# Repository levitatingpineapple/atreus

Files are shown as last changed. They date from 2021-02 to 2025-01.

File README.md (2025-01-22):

# Atreus

A keyboard with 42 key [Atreus](https://atreus.technomancy.us) layout. Uses [Kailh Choc](http://www.kailh.com/en/Products/Ks/CS/) low profile switches with hot-swap sockets. Compatible with ProMicro type controllers, but designed to be used with [Nice!Nano](https://nicekeyboards.com/nice-nano). Capable of n-key rollover. There is enough spacing between keys to fit all of the commonly available keycaps - transparent, flat and concave.

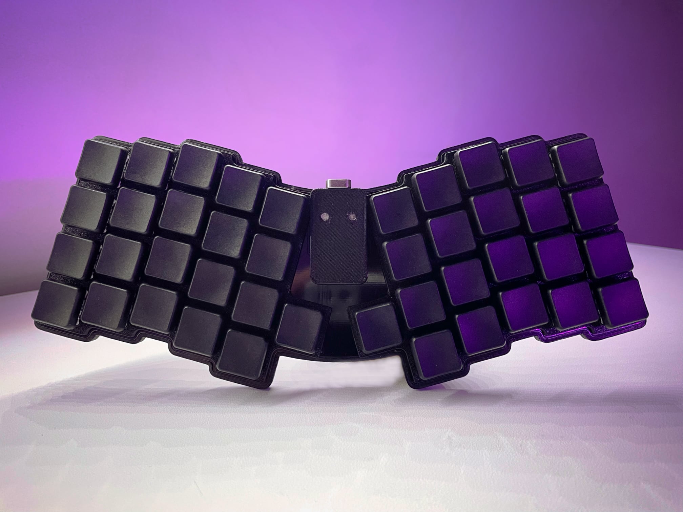
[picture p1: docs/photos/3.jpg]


## Firmware

[Nice!Nano](https://nicekeyboards.com/nice-nano) is best supported by [ZMK](https://zmk.dev) Configuration for this board is hosted in the [levitatingpineapple/atreus-zmk](https://github.com/levitatingpineapple/atreus-zmk) repo.
To build a different keymap - clone the repo and update `.keymap` file as needed.
The firmware will be build using [Build ZMK firmware](https://github.com/levitatingpineapple/atreus-zmk/actions/workflows/build.yml) action.

## Materials

| Name | Part | Size | Amount |
| --- | --- | --- | --- |
| Switch | [CPG135001D0X](docs/switch.pdf)  | - | 42 |
| Socket | [CPG135001S30](docs/socket.pdf)  | - | 42 |
| Diode | [1N4148](docs/diode.pdf) | SOD123 | 42 |
| Controller | [nice!nano](docs/controller.png) | - | 1 |
| Battery | XZK 301230 | 30x12x3.0mm | 1 |
| Bolt | M2 Hex | 4mm | 8 |
| Machine Headers | Mill-Max | 13p 3mm | 2 |

### PCB

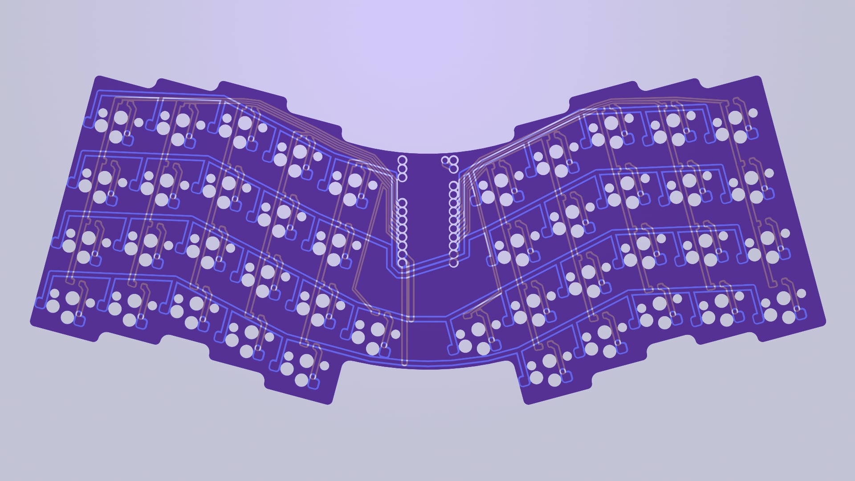
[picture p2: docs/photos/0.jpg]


- ⚠️ No power switch for the battery
- For every switch has a diode, soldered where an backlight LED would normally be located, providing n-key rollover.

### Sockets

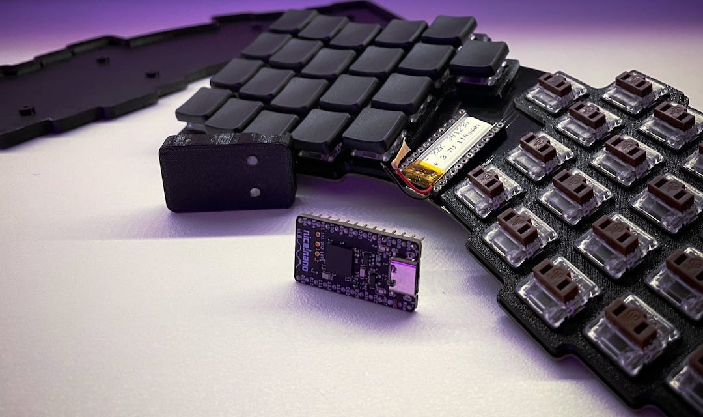
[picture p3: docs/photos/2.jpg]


- The PCB has 1.5mm wide holes for mounting the controller socket. This allows soldering machine headers flush with the board. The nice!nano controller originally ships with low profile headers, which won't fit the battery underneath the controller, if soldered in this manner. Therefore a pair of 3mm tall headers had to be separately ordered.

### Case

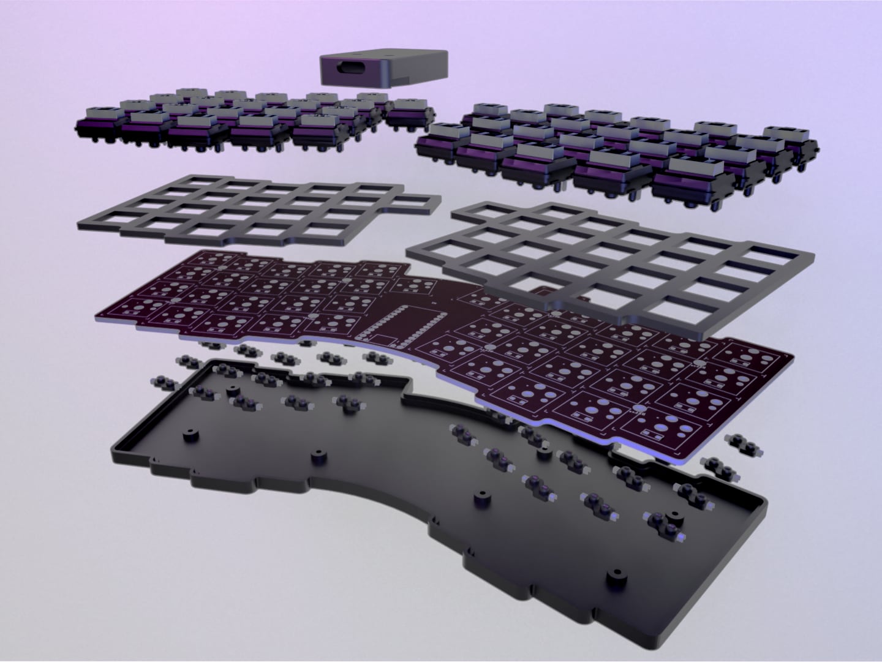
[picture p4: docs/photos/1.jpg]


- All 3d printing was done with 0.4mm nozzle at 0.2mm layer height from PETG.
- The bottom case is attached using eight 4mm long M2 bolts.
- Added feet using 1mm thick rubber tape

### Led

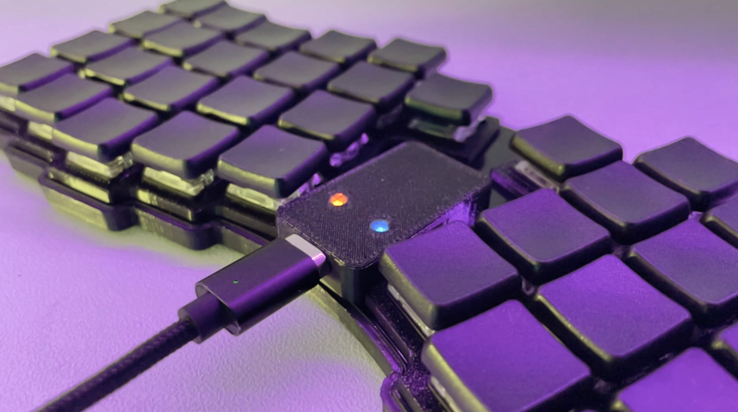
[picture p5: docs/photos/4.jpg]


- In the nice!nano's cover there are two openings for the LEDs. They can be filled with a dab of hot-glue before the print is removed form the bed to get a more diffused look _...for science, you monster._

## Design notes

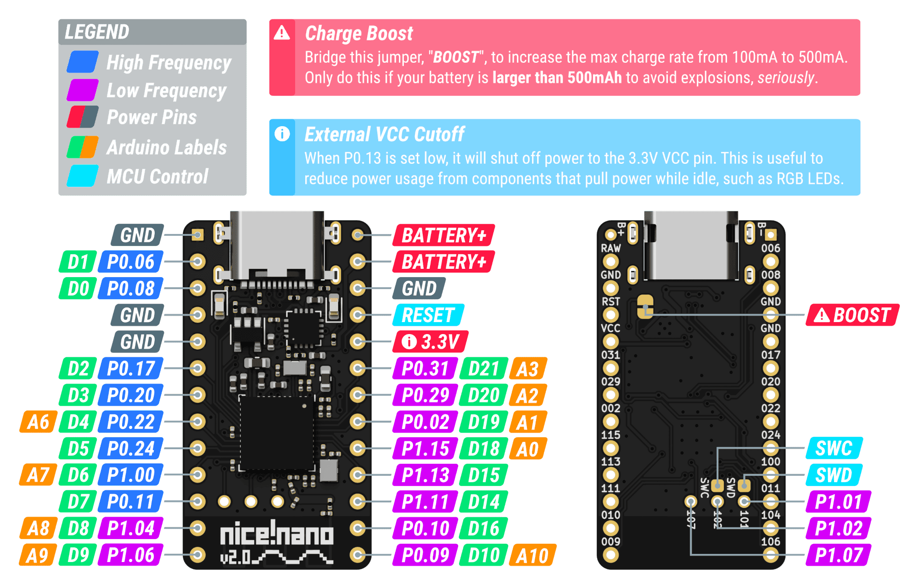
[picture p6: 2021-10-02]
docs/controller.png

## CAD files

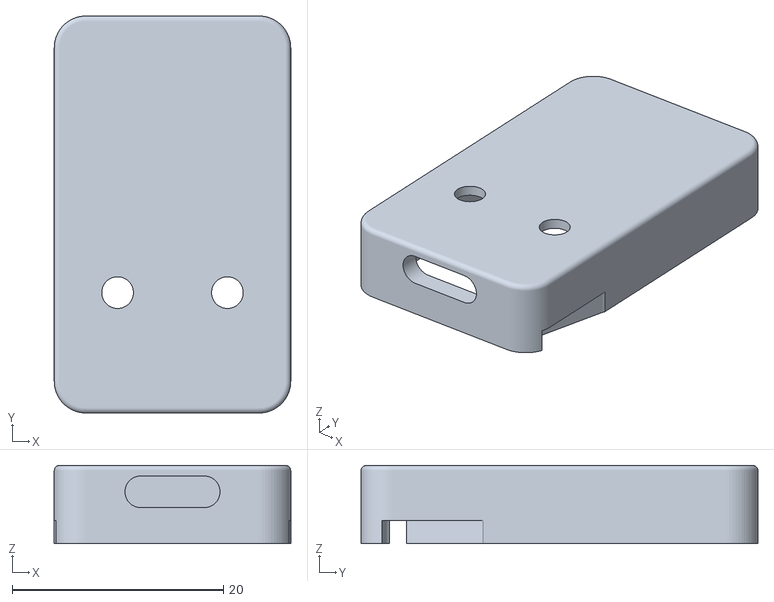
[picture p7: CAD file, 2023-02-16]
export/case/controller.stl
22.4 x 37.6 x 7.40

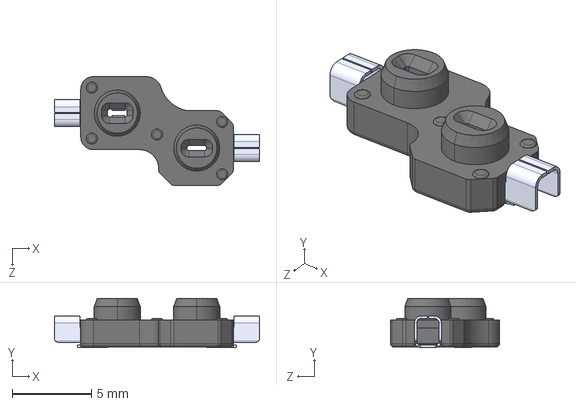
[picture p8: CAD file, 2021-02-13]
project/3DModels/choc_socket.step
12.9 x 3.09 x 6.85 mm
pin x 2
socket

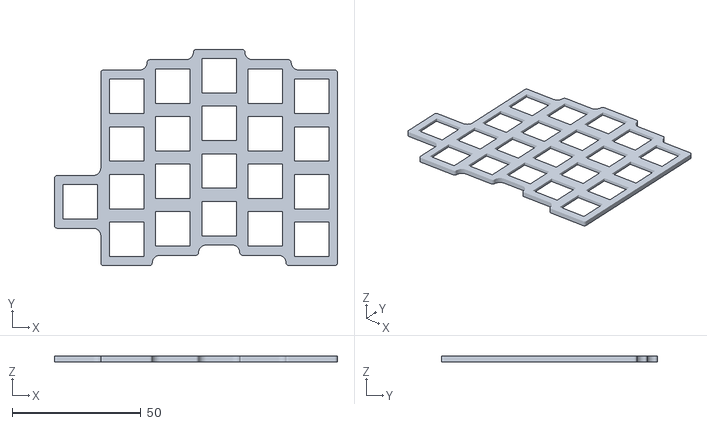
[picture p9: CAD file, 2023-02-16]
export/case/topRight.stl
110.0 x 84.0 x 2.20

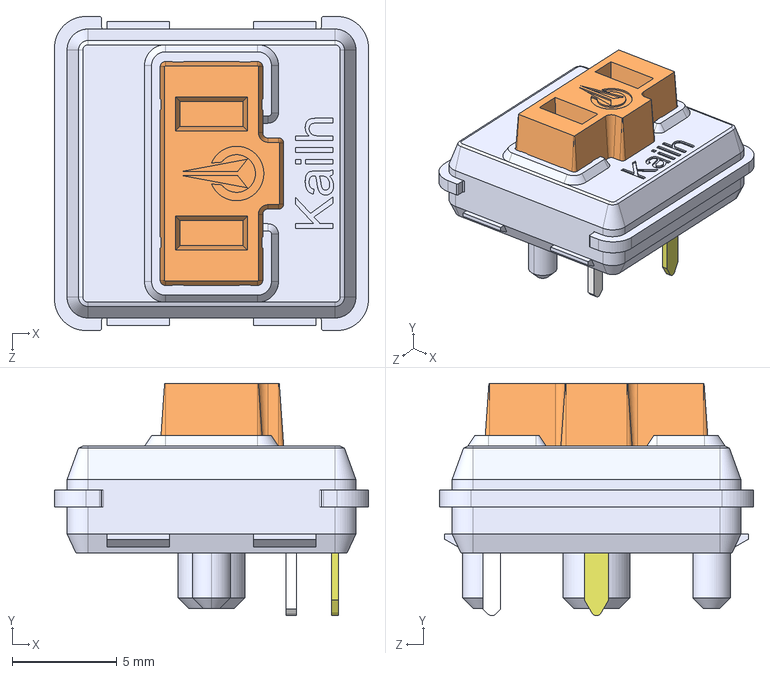
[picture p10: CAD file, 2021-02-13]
project/3DModels/choc_switch.igs
15.0 x 11.1 x 15.0 mm

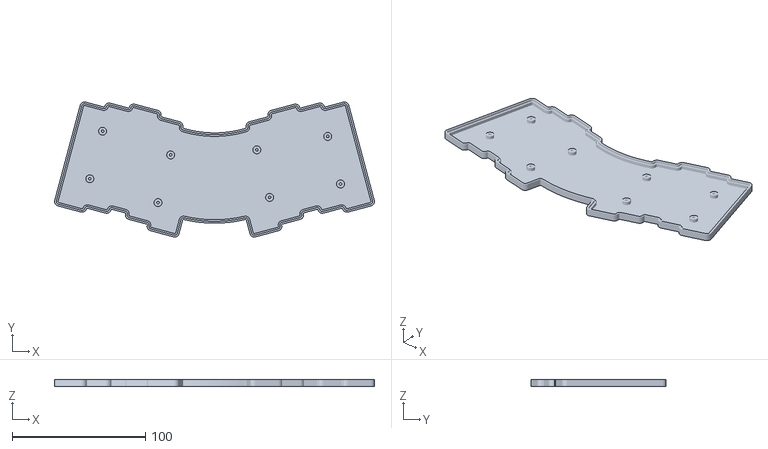
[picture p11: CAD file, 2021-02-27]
export/case/bottom.stl
240.2 x 101.5 x 5.00

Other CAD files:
export/case/topLeft.stl

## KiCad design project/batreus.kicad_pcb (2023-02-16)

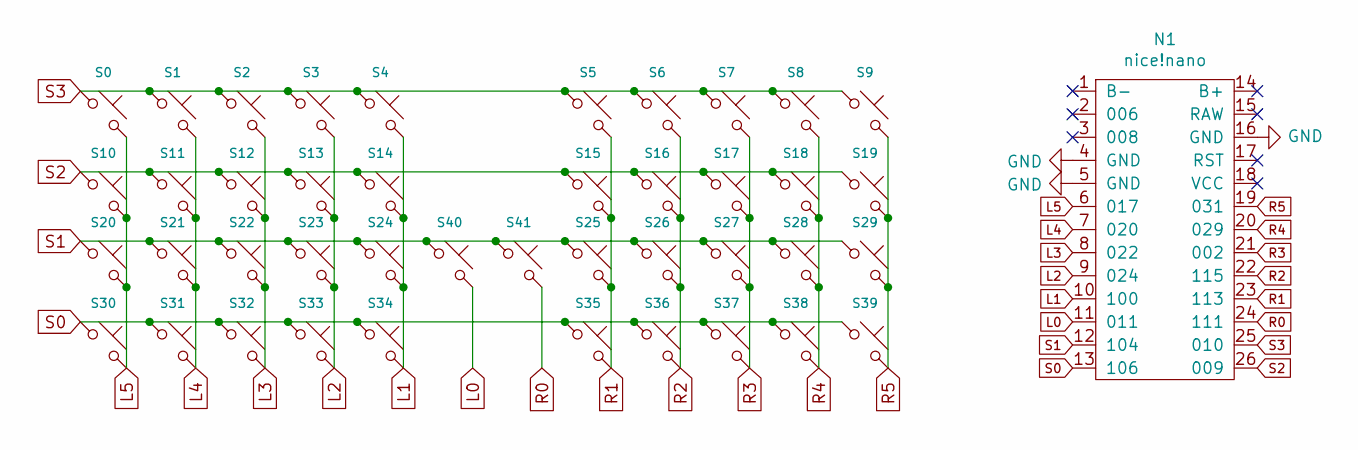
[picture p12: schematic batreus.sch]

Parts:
N1: nice!nano
S0, S1, S2, S3, S4, S5, S6, S7, S8, S9, S10, S11, S12, S13, S14, S15, S16, S17, S18, S19, S20, S21, S22, S23, S24, S25, S26, S27, S28, S29, S30, S31, S32, S33, S34, S35, S36, S37, S38, S39, S40, S41: K; HotChoc

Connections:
GND: N1.4 (GND), N1.5 (GND), N1.16 (GND)
L0: N1.11, S40.2
L1: N1.10 (100), S4.2, S14.2, S24.2, S34.2
L2: N1.9 (024), S3.2, S13.2, S23.2, S33.2
L3: N1.8 (022), S2.2, S12.2, S22.2, S32.2
L4: N1.7 (020), S1.2, S11.2, S21.2, S31.2
L5: N1.6 (017), S0.2, S10.2, S20.2, S30.2
R0: N1.24 (111), S41.2
R1: N1.23 (113), S5.2, S15.2, S25.2, S35.2
R2: N1.22 (115), S6.2, S16.2, S26.2, S36.2
R3: N1.21 (002), S7.2, S17.2, S27.2, S37.2
R4: N1.20 (029), S8.2, S18.2, S28.2, S38.2
R5: N1.19 (031), S9.2, S19.2, S29.2, S39.2
S0: N1.13 (106), S30.1, S31.1, S32.1, S33.1, S34.1, S35.1, S36.1, S37.1, S38.1, S39.1
S1: N1.12 (104), S20.1, S21.1, S22.1, S23.1, S24.1, S25.1, S26.1, S27.1, S28.1, S29.1, S40.1, S41.1
S2: N1.26 (009), S10.1, S11.1, S12.1, S13.1, S14.1, S15.1, S16.1, S17.1, S18.1, S19.1
S3: N1.25 (010), S0.1, S1.1, S2.1, S3.1, S4.1, S5.1, S6.1, S7.1, S8.1, S9.1

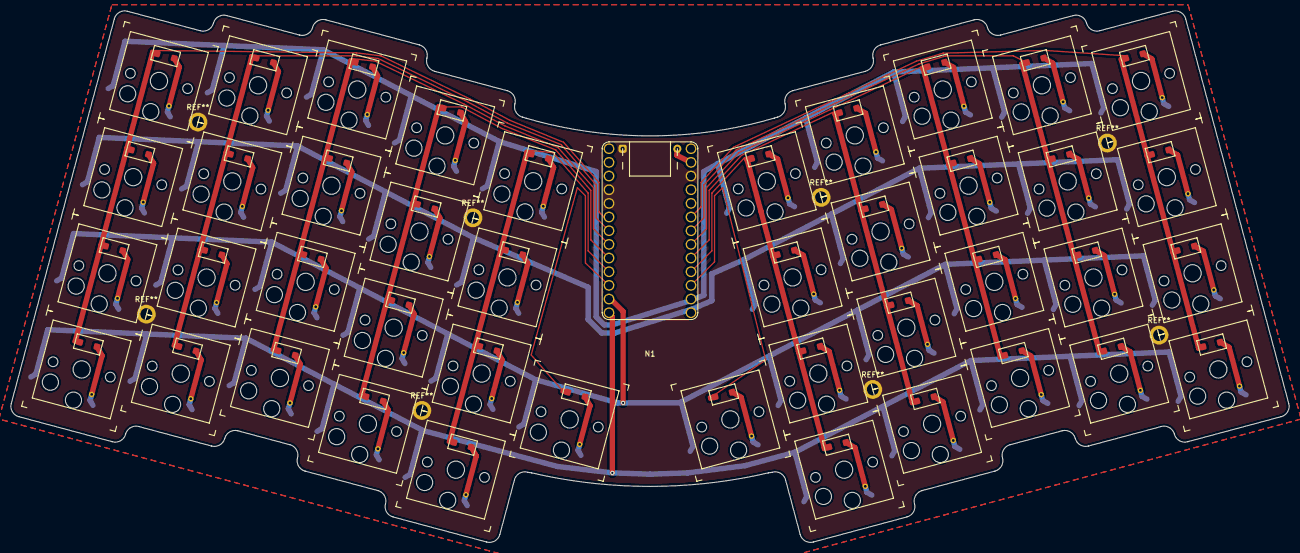
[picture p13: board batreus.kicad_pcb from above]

Board: 2 copper layers, 237.5 x 98.8 mm, 43 parts (0 on the bottom side), 17 nets.

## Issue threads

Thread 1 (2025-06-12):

License?

cceckman, 2025-06-12:
This looks like a really neat keyboard! I like my (tall) Atreus & several choc keyboards - a wireless-friendly model seems like a great upgrade!

Can you clarify what license these materials are under? e.g. the original Atreus is released under the GPL ([per the site](https://atreus.technomancy.us/)).

(Specifically, I'm wondering whether it would be fine to do a PCB run of these and/or case redesigns.)

Thanks!

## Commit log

2021-02-13 Add 3d models.
    [batreus.kicad_pcb, choc_socket.step, choc_switch.igs]
2021-02-27 Add case model
    [case.stl]
2023-02-16 New case. Updated readme
    [batreus.kicad_pcb, controller.stl, topLeft.stl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]
2023-04-01 Update Readme
    Update markdown to show in the pin.
